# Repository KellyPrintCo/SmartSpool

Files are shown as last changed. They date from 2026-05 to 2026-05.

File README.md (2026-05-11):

# SmartSpool

> **Automatic RFID filament identification for the Bambu Lab AMS 2 Pro.**
> Built and maintained by [Kelly Print Co](https://www.etsy.com/shop/KellyPrintCo).

Load a tagged spool into AMS Slot 1 and your printer instantly knows exactly
what filament is loaded — material, brand, color, and temperatures. No screen
tapping, no manual entry.

This repo contains the open-source firmware, browser extension, and 3D-printable
files. Want the convenience of a pre-built kit? Get one on [Etsy](https://www.etsy.com/shop/KellyPrintCo).

## What's in this repo

| Folder | What it is |
|---|---|
| [`firmware/`](firmware/) | ESP32 firmware — the brain of SmartSpool |
| [`extension/`](extension/) | Print Wizard Chrome extension — adds a guided print button to MakerWorld |
| [`hardware/`](hardware/) | 3D-printable mount STL/3MF files |
| [`version.json`](version.json) | Update manifest — devices fetch this to check for new firmware |
| [`docs-OTA-process.md`](docs-OTA-process.md) | How firmware updates work and how to publish them |

## Quick start

**If you bought a kit:** unbox it, follow the setup card. You're done.

**If you're building it yourself from these files:**

1. **Print the mount** (PETG recommended) from `hardware/stl/`
2. **Wire it up** — ESP32 + MFRC522, see `firmware/README.md` for the wiring diagram
3. **Flash the firmware** — open `firmware/SSOLite.ino` in Arduino IDE 2.x and click Upload
4. **Install the extension** — load `extension/` unpacked in Chrome
5. **Configure** — connect to the `SmartSpool-Setup` Wi-Fi, open `192.168.4.1`, enter your printer info

Full instructions in [`firmware/README.md`](firmware/README.md).

## Features

- **Automatic RFID slot 1 assignment** — tap a tagged spool, AMS updates instantly
- **Custom filament profiles** — unlimited material/brand/color combinations via web UI
- **Auto tag rewrite** *(optional)* — if you change filament info on the printer touchscreen, SmartSpool can update the RFID tag to match
- **Over-the-air updates** — firmware updates push automatically through the Print Wizard extension or device web UI
- **MakerWorld integration** — Print Wizard adds a guided "Print" button that walks beginners through filament check, build plate selection, and bed prep

## Requirements

- Bambu Lab **AMS 2 Pro**
- Bambu Lab **X1, P1, or A1 series** printer
- **LAN Only Mode** and **Developer Mode** enabled on the printer
- 2.4GHz WiFi network
- Components per [`firmware/README.md`](firmware/README.md) parts list

## Compatibility

| Bambu hardware | Status |
|---|---|
| AMS 2 Pro | ✅ Fully supported |
| AMS Lite | ❌ Different mount geometry |
| Original AMS | ❌ Different mount geometry |
| X1C / X1 Carbon | ✅ |
| P1S / P1P | ✅ |
| A1 / A1 mini | ✅ |
| H2D | Not yet tested |

## Releases

Firmware binaries for every release are attached to GitHub releases. The
current stable version is shown in [`version.json`](version.json).

Devices running v1.3.0 or later receive future updates automatically over WiFi.

## License

MIT License — see [LICENSE](LICENSE). You're free to fork, modify, sell, and
distribute. Attribution appreciated but not required.

This project is **not affiliated with Bambu Lab**. SmartSpool uses Bambu's
documented LAN-mode MQTT API and does not modify or interfere with the printer
firmware in any way.

## Contributing

Pull requests and issues welcome. See [`.github/ISSUE_TEMPLATE/`](.github/ISSUE_TEMPLATE/)
for the bug report and feature request templates.

## Support

- **Found a bug?** Open an [issue](https://github.com/KellyPrintCo/SmartSpool/issues/new/choose)
- **Need help with your kit?** Email Kelly Print Co via your Etsy order
- **Want to chat?** Discussions tab on this repo

## Acknowledgments

- Bambu Lab — for building the printer this works with
- The OrcaSlicer team — for documenting the MQTT protocol
- The 3D printing community on r/BambuLab — for being the most helpful corner of the internet

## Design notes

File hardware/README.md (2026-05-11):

# Hardware

This folder holds the 3D-printable parts that make up SmartSpool AMS.

## Files in `stl/`

| File | Description |
|---|---|
| `smartspool-mount.stl` | The main mount that clips into the AMS 2 Pro side slits |
| `smartspool-mount.3mf` | Same file in Bambu 3MF format (preserves print settings) |

## Print settings

- Material: **PETG** (PLA works but warps if AMS drying mode is used)
- Layer height: 0.2mm
- Infill: 20% gyroid
- Walls: 3 perimeters
- Supports: none required if printed in default orientation

## Wiring diagram

See `wiring-diagram.png` (if present) or the wiring section in the firmware README.

## Where to get the files

- This repo: `hardware/stl/` directory
- MakerWorld: search "SmartSpool AMS" for the latest version with photos

## Print yourself, or buy a kit

The STL files here are free to download and print. If you'd rather get a
pre-assembled, pre-flashed kit, look for **Kelly Print Co** on Etsy.

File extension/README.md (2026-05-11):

# MakerWorld Print Wizard for SSO-Lite

A Chrome extension that adds a "Print Wizard" button to MakerWorld model pages
and walks beginners through the whole printing process — checking what
filament is loaded, picking the right one, tagging the spool, choosing the
build plate, and handing the model off to Bambu Studio.

It pairs with **SmartSpool OS Lite (SSO-Lite)** running on your ESP32 + MFRC522
reader, talks to it over your LAN, and uses Studio's existing deeplink to send
the model to your printer. No cloud, no server, no extra software.

## How it works

```
You browse a model on MakerWorld
        │
        │  ① extension injects "Print Wizard" button
        ▼
  Wizard opens as an overlay
        │
        │  ② calls SSO-Lite over LAN (HTTP) to read AMS Slot 1
        ▼
  Wizard checks if the loaded filament matches what the model needs
        │
        │  ③ if not, you pick a profile and tap a tag — SSO-Lite writes the
        │     tag and pushes the new filament to AMS Slot 1 over MQTT
        ▼
  Wizard confirms the printer is ready (plate, bed prep)
        │
        │  ④ clicks MakerWorld's own "Open in Studio" link
        ▼
  Bambu Studio opens with the model — you click Print
```

The extension never talks to the printer directly. All printer communication
goes through the SSO-Lite firmware (which you already have running for AMS
auto-assignment). Studio handles the actual print job.

## Install

This is an **unpacked extension** — Chrome's developer load mode. Five steps:

1. **Update SSO-Lite firmware to v1.1.0** (see `SSOLite.ino` in the SSO-Lite
   project folder). The new version adds CORS headers (so the browser can call
   it) and an mDNS responder (so the extension can find it as `ssolite.local`).
   Re-flash from Arduino IDE; everything keeps working as before.

2. Download or clone this folder somewhere stable on your Mac/PC. Don't put
   it in Downloads or it'll go away when you clean up.

3. Open Chrome and go to `chrome://extensions`.

4. Toggle **Developer mode** on (top-right corner of that page).

5. Click **Load unpacked** and pick the `mw-print-wizard/` folder.

The extension's icon (a green spool) should appear in your toolbar. If
you don't see it, click the puzzle-piece icon and pin it.

## First use

1. Click the toolbar icon. The popup shows whether it can reach SSO-Lite.
2. If it says "unreachable", click **Settings**:
   - Most users: leave address as `ssolite.local`. This works on macOS and
     iOS out of the box, on Windows 10+ it usually works, on Linux it works
     if you have Avahi/`avahi-daemon` installed.
   - If `ssolite.local` doesn't resolve, replace it with the device's IP
     address (you can find this in your router's DHCP table or in the
     SSO-Lite serial monitor at boot).
   - Click **Test connection**. You should see "Connected (vX.X.X)."
   - Click **Save**.
3. Open any model page on `https://makerworld.com/...`. Look for the green
   **Print Wizard** button next to MakerWorld's regular Print/Open in Studio
   button. (If MakerWorld redesigns and the button can't find an anchor, it
   floats in the bottom-right corner instead.)
4. Click it. Walk through the wizard.

## What the wizard does, step by step

| Step | What happens |
|---|---|
| **Welcome** | Shows the model title, image, recommended materials and plate (scraped from the page). |
| **Connect** | Verifies SSO-Lite is reachable. Shown only on first use; skipped after the first successful connection in a wizard session. |
| **Filament check** | Asks SSO-Lite what's currently in AMS Slot 1, compares against the page's recommended materials. Big green ✓ if they match, big yellow ⚠ if they don't. |
| **Pick filament** *(only if mismatched)* | Shows your SSO-Lite profile library as a grid of color-coded cards. Profiles whose material matches the model are pinned to the top with a "recommended" badge. |
| **Load & tag** *(only if swapping)* | Tells you to load the spool and tap the tag. Live status — polls SSO-Lite every 800ms, advances when a successful read of the chosen profile is detected. |
| **Build plate** | Shows what plate the model wants, with a beginner-friendly explanation. Requires you to tick "the right plate is on my printer" before continuing. |
| **Quick prep** | Four-item checklist: clean bed, plate seated, nozzle clear, door position. All four must be ticked. |
| **Send to Studio** | Clicks MakerWorld's existing "Open in Studio" link. Studio opens with the model loaded; you press Print there. |
| **Done** | A short reminder to watch the first layer. |

## What about the "MQTT verification failed" error?

The wizard inherits SSO-Lite's solution: your printer needs to be in **LAN
Only Mode + Developer Mode**. Without it, MQTT commands (the AMS slot
assignment) get rejected. See the SSO-Lite README's troubleshooting section.

If you're keeping cloud mode (e.g. you need Bambu Handy via cloud), turn off
SSO-Lite's auto-assign and the wizard will still walk you through everything
useful — it just won't push the AMS change. You set the slot manually in
Studio.

## Files

| File | Purpose |
|---|---|
| `manifest.json` | MV3 manifest. Permissions, content-script targets, web-accessible resources. |
| `background.js` | Service worker. Owns the SSO-Lite HTTP client and the settings store. Everything else talks to it via `chrome.runtime.sendMessage`. |
| `content.js` | Injected into MakerWorld pages. Detects model pages, scrapes metadata, injects the button, opens the wizard iframe. |
| `content.css` | Button + iframe overlay styling. Namespaced with `.sso-mw-` to avoid collisions with MakerWorld's own classes. |
| `wizard.html` / `wizard.js` / `wizard.css` | The wizard itself. Runs inside an iframe that the content script injects. Communicates with the parent (content script) via `postMessage` and with SSO-Lite via the background worker. |
| `popup.html` / `popup.js` / `popup.css` | Toolbar popup — health check + quick links. |
| `options.html` / `options.js` | Settings page — SSO-Lite hostname/IP/port, test button. |
| `icons/` | 16/48/128 PNG icons. |

## Permissions explained

| Permission | Why we need it |
|---|---|
| `storage` | Remember your SSO-Lite hostname between sessions. |
| `host_permissions` for `*.makerworld.com` | Inject the content script on model pages. |
| `host_permissions` for `http://ssolite.local/*` and `http://*/*` | Talk to SSO-Lite over LAN. The wildcard `http://*/*` is there so users can use a raw IP (which we can't predict). MV3 service workers need explicit host permission to fetch cross-origin. |

The extension does **not** read or send anything to any cloud service. All
network traffic goes either to MakerWorld (you're already there) or to your
own SSO-Lite device on your LAN.

## Troubleshooting

**"Print Wizard" button never appears on MakerWorld**
- Open the page DevTools → Console. The content script logs once at load.
- MakerWorld may have changed their DOM. As a fallback the button auto-floats
  to the bottom-right corner if the script can't find the regular Print
  button anchor.
- Make sure the URL matches `/models/` — the script ignores other pages.

**Wizard says "Couldn't reach SSO-Lite"**
- Open the toolbar popup. If it's also unreachable from there:
  - Open `http://ssolite.local/` directly in a new tab. If that doesn't load,
    you have an mDNS issue — switch to the IP in Settings.
  - Make sure SSO-Lite is on the same Wi-Fi as your computer. Some "guest"
    networks block client-to-client traffic.
  - Check the SSO-Lite serial monitor — does it print `[mDNS] http://ssolite.local/` at boot?

**"Tag write" times out**
- The wizard polls for 65 seconds. If you didn't tap a tag in time, click
  back and re-pick the profile.
- Make sure the SSO-Lite reader's LED is doing its boot-blink — if it
  isn't, the ESP32 isn't powered.

**Studio doesn't open at the end**
- Make sure Bambu Studio is installed (`bambustudio://` deeplinks need it).
- If MakerWorld's own "Open in Studio" button doesn't work either, the
  problem is upstream of us.
- The wizard shows a fallback message in the "Send" step if it can't find
  the link.

## License

Same as SSO-Lite. Not affiliated with Bambu Lab or MakerWorld.

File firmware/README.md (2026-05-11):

# SmartSpool OS Lite (SSO-Lite) — Complete Build Guide

ESP32 + MFRC522 → Bambu Lab AMS Slot 1 auto-assignment over MQTT/TLS.

This document is the full design, build, troubleshooting, and productization guide.
The firmware itself lives in `SSOLite.ino` and `web_pages.h` — open them in Arduino IDE
and flash. No other configuration is needed at compile time; everything is set through
the on-device web UI.

---

## What's New in v1.3.0

**Over-the-air firmware updates** *(new feature)*

SmartSpool can now update its own firmware over WiFi — no USB cable, no
Arduino IDE, no manual flashing. The update prompt appears automatically when
Print Wizard connects to a device running an older version, or in the device's
own web UI under Controls → Firmware Update.

How it works:
1. SmartSpool checks `version.json` on GitHub for the latest published firmware
2. If an update is available, the web UI / Print Wizard shows an update prompt
3. The new firmware binary downloads from GitHub Releases
4. The binary uploads to the SmartSpool device over LAN (~5 seconds)
5. SmartSpool's `Update` library writes it to the OTA partition
6. Device reboots and comes back on the new firmware (~10-15 seconds)
7. Web UI / Print Wizard auto-reconnects and verifies the new version

The whole process takes 25-40 seconds end to end on a typical home network.

Configuration:
- Firmware author edits `version.json` in the GitHub repo to publish updates
- New endpoint `POST /api/update` accepts firmware binaries
- New endpoint `GET /api/update/status` reports upload progress
- See `OTA_RELEASE_GUIDE.md` for the full release publishing process

**Important chicken-and-egg note:** Devices running firmware older than v1.3.0
do not have the OTA endpoint and must be flashed to v1.3.0 via USB once.
After that, all future updates can be OTA. Ship pre-flashed units with v1.3.0+
to avoid customers ever encountering this.

---

## What's New in v1.2.0

**Auto-rewrite on touchscreen change** *(new, off by default)*

When enabled, if you change slot 1 filament info on the printer's touchscreen
(color, brand, material, temps), SmartSpool catches the change via MQTT and
queues a rewrite of the RFID tag. The next time you tap that tag on the reader,
the new info is written to the tag automatically — no need to use the SmartSpool
web UI to manually update each tag.

How it works:
1. You scan tag A → SmartSpool reads it and applies its profile to slot 1.
2. You change filament info on the touchscreen (different color, brand, etc.).
3. The printer publishes the new state over MQTT.
4. SmartSpool detects this is *different* from what it just set, and queues the
   new info as a "pending rewrite" tied to tag A's UID.
5. Next time tag A is presented to the reader, SmartSpool writes the new info
   to the tag before doing the normal scan flow. Tag now persists the change.

Off by default because some users intentionally do one-off touchscreen overrides
they don't want remembered. Enable it via:
- Web UI → Setup tab → "Auto-rewrite tag on touchscreen change"
- Web UI → Controls → "Toggle Auto-Rewrite" button
- API: `POST /api/rewrite`

A pending rewrite is shown on the dashboard with a yellow card; you can cancel
it before scanning.

**Side-slit mounting** *(mechanical change)*

The recommended mount location is now the side slits on the *outside* of the
AMS 2 Pro, not the desiccant slot. This avoids any conflict with the AMS lid
opening, the drying chamber, or internal cable routing. The reader still has
range to read tags on a spool loaded into slot 1.

---

## 1. System Architecture

```
 ┌──────────────┐     SPI      ┌──────────────────┐    Wi-Fi/TLS   ┌─────────────┐
 │  RFID Tag    │◀────────────▶│      ESP32       │───────────────▶│   Bambu     │
 │ (MIFARE 1K)  │   MFRC522    │  (SSO-Lite FW)   │   MQTT 8883    │   Printer   │
 └──────────────┘              │                  │   bblp / LAN   │  (X1/P1/A1) │
                               │  • Web UI :80    │                │             │
                               │  • Profile DB    │                │  AMS Slot 1 │
                               │  • UID fallback  │◀───────────────│  (tray 0,0) │
                               └──────────────────┘   /report      └─────────────┘
```

### Data flow
1. Tag enters RF field → MFRC522 returns UID and authenticates sector 1 with default key A.
2. ESP32 reads blocks 4–6 (48 bytes), validates magic header `SSO1`, parses compact key=value payload.
3. The parsed Bambu code (e.g. `GFL99`) is resolved against the on-device profile database to canonicalise temps and color.
4. ESP32 publishes `ams_filament_setting` to `device/{serial}/request` over MQTT/TLS.
5. Printer applies the change; the next `/report` push confirms the new tray state.

### Tag lifecycle
```
   blank tag ──► [Web UI: Queue Write] ──► written tag ──► scanned ──► assigned ──► reused
                                                  │                            ▲
                                                  └───── Edit ─────────────────┘
```

### State machine
| State | Trigger | Exit |
|---|---|---|
| BOOT | power-on | config loaded → WIFI_CONNECTING |
| WIFI_CONNECTING | startup / disconnect | got IP → MQTT_CONNECTING |
| MQTT_CONNECTING | TCP up | broker ack → IDLE |
| IDLE | nothing happening | tag presented → READING; UI write queued + tag → WRITING |
| READING | card detected | parse OK → ASSIGNING; parse fail → UID fallback or ERROR |
| WRITING | pending write fulfils | success → IDLE; failure → ERROR |
| ASSIGNING | auto-assign on | publish OK → IDLE; publish fail → retry queue |
| ERROR | any failure | LED blink, log, return to IDLE |

### Failure handling
- **Wi-Fi drop**: 10 s reconnect loop; web UI stays up on STA IP, AP fallback if SSID unconfigured.
- **MQTT drop**: 5 s reconnect; pending assign request is held in `g_pending` and re-sent on reconnect with exponential backoff (5/10/20/40/80 s).
- **Tag corruption**: checksum mismatch logs a warning but the parser is forgiving — partial fields recover. If the magic header itself is gone, UID-fallback table maps `(UID → code)`.
- **AMS override / drift**: `processReport()` watches the printer's reported tray 0 code; if it differs from the last-scanned profile, SSO-Lite re-applies once per 30 s.
- **Bambu official RFID detected**: non-Classic tag types (NTAG/Ultralight) trigger `g_officialTagDetected = true`, auto-assign is suppressed, and the dashboard pill turns yellow.

---

## 2. Hardware Design

### Parts list
| Item | Qty | Notes |
|---|---|---|
| ESP32 DevKit V1 / WROOM-32 / NodeMCU-32S | 1 | Any 30/38-pin board with native USB |
| MFRC522 RFID module | 1 | Common red breakout, 3.3 V logic |
| MIFARE Classic 1K white card / sticker | n | The "blue" 13.56 MHz cards from any vendor |
| Dupont jumpers (F-F) | 7 | One per signal + VCC/GND |
| USB-C / micro-USB cable | 1 | Power + flashing |
| 3D-printed mount (Section 13) | 1 | optional but recommended |

### Wiring (ESP32 ↔ MFRC522)

| MFRC522 | ESP32 GPIO | Function | Notes |
|---|---|---|---|
| SDA / SS | **GPIO 5** | SPI chip-select | safe pin |
| SCK | **GPIO 18** | SPI clock | VSPI default |
| MOSI | **GPIO 23** | SPI MOSI | VSPI default |
| MISO | **GPIO 19** | SPI MISO | VSPI default |
| RST | **GPIO 22** | reset | safe pin |
| GND | **GND** | ground | |
| 3V3 | **3V3** | **3.3 V ONLY** | see warning below |
| IRQ | (not connected) | — | unused; we poll |

> ⚠️ **3.3 V ONLY.** Many MFRC522 boards say "3.3 V or 5 V" on the silkscreen.
> The MFRC522 IC itself is **only** 3.3 V. Powering from 5 V will work briefly and then
> kill the chip. Use the ESP32's 3V3 pin (which can sink ~500 mA — plenty for this module).

### Pins to AVOID on ESP32

| Pin | Why |
|---|---|
| GPIO 0 | Boot strap — must be HIGH at reset to boot from flash |
| GPIO 2 | Boot strap & on-board LED on most boards |
| GPIO 12 | Boot strap — wrong level locks board into 1.8 V flash mode |
| GPIO 15 | Boot strap — pulled up enables verbose serial spam |
| GPIO 6–11 | Connected to internal SPI flash — touching these bricks the boot |
| GPIO 34–39 | Input-only, no internal pull-ups |

The pins chosen (5, 18, 19, 22, 23) are all general-purpose and free of strap conflicts.

### Physical placement near AMS Slot 1

For an AMS or AMS Lite, the ideal mount point is on the **outer face of the slot 1
filament guide**, with the MFRC522 antenna oriented so that a tag stuck to the side of
the spool (or a separate tag on a hook) passes within ~25 mm of the coil during loading.
Tag read range with a Classic 1K card and a default-tuned MFRC522 is ~30–40 mm.

A 3D-printable bracket is described in Section 13.

---

## 3. RFID Tag System

### A. Storage strategy

MIFARE Classic 1K = 16 sectors × 4 blocks × 16 bytes = 1024 bytes total.

```
Sector 0  Block 0   manufacturer block (UID + data) — READ ONLY
Sector 0  Block 1   usable, but we avoid (some clones break here)
Sector 0  Block 2   usable, but avoided
Sector 0  Block 3   sector trailer (keys + ACL) — DO NOT WRITE
Sector 1  Block 4   ◄── SSO data block A
Sector 1  Block 5   ◄── SSO data block B
Sector 1  Block 6   ◄── SSO data block C
Sector 1  Block 7   sector trailer — DO NOT WRITE
Sectors 2-15        free for future extensions
```

We use **only sector 1**, blocks 4–6 (48 bytes total). This is enough for the compact
encoded format and leaves the rest of the card available for future features (usage
counters, cloning detection, etc.).

### B. Data formats

#### Compact (on-tag, what SSO-Lite reads/writes)
```
M=PLA;C=GFL99;X=000000;B=Overture;N=210;D=60
```
Fields:
- `M` — material short name (PLA / PETG / ABS / TPU / PA / PC / PVA)
- `C` — Bambu generic code (`tray_info_idx`, e.g. `GFL99`)
- `X` — color RGB hex (no `#`, no alpha)
- `B` — brand name (≤ 19 chars)
- `N` — nominal nozzle temp (printer recomputes range)
- `D` — bed temp

The parser is order-independent and tolerant of missing optional fields.

#### Full JSON (used in HTTP API + persistent storage)
```json
{
  "name": "Overture PLA Matte",
  "material": "PLA",
  "code": "GFL99",
  "color": "1C1C1C",
  "brand": "Overture",
  "nozzle_min": 200,
  "nozzle_max": 220,
  "bed": 60,
  "flow_x1000": 1000
}
```

#### Tag block layout (48 bytes)
| Bytes | Content |
|---|---|
| 0–3 | magic `S S O 1` (`0x53 0x53 0x4F 0x31`) |
| 4 | version (`0x01`) |
| 5 | payload length N (≤ 41) |
| 6 .. 5+N | ASCII payload |
| 5+N .. 46 | zero padding |
| 47 | XOR checksum of bytes 0..46 |

### C. Tag security
- **Keys:** SSO-Lite uses the default factory key A (`FF FF FF FF FF FF`) on sector 1.
  Keeping the default keeps tags re-flashable from any standard tool and avoids the
  *brick-on-typo* failure mode. If you want to lock tags, you can change Key A in the
  sector trailer — but **never touch block 7 unless you understand MIFARE access bits**;
  one bad write permanently locks the sector.
- **Overwrite protection:** The web UI requires an explicit "Queue Write" press; the
  reader will only write within a 60 s window per request. A tag presented outside that
  window is read-only.
- **UID fallback:** every successful write also stores `(UID → tray_info_idx)` in the
  device's UID map. If the data blocks ever go bad, SSO-Lite still recognises the spool
  by UID and applies the right profile.

---

## 4. Filament Profile System

Profiles live in NVS (`Preferences`) and are loaded into `g_profiles[]` at boot.
On first boot, the firmware seeds a starter set:

| Name | Material | Code | Color | Brand | Nozzle | Bed |
|---|---|---|---|---|---|---|
| Generic PLA Black  | PLA  | GFL99 | #000000 | Generic  | 190–230 | 60 |
| Generic PLA White  | PLA  | GFL99 | #FFFFFF | Generic  | 190–230 | 60 |
| Generic PLA Red | PLA  | GFL99 | #C8161D | Generic  | 190–230 | 60 |
| Generic PLA Blue | PLA  | GFL99 | #0066CC | Generic  | 190–230 | 60 |
| Overture PLA Matte | PLA  | GFL99 | #1C1C1C | Overture | 200–220 | 60 |
| Generic PETG | PETG | GFG99 | #0099A8 | Generic  | 230–255 | 75 |
| Generic PETG Black | PETG | GFG99 | #000000 | Generic  | 230–255 | 75 |
| Generic ABS | ABS  | GFB99 | #F2F2F2 | Generic  | 240–270 | 95 |
| Generic TPU 95A | TPU  | GFU99 | #FFFFFF | Generic  | 220–240 | 50 |
| Generic PA (Nylon) | PA | GFN99 | #303030 | Generic  | 260–290 | 80 |
| Generic PC | PC | GFC99 | #F0F0F0 | Generic  | 270–290 | 100 |
| Generic PVA Sup. | PVA  | GFS99 | #F4E2B8 | Generic  | 200–210 | 60 |

**Bambu generic codes** are 5-character `tray_info_idx` values that tell the printer to
treat the slot as the corresponding generic profile (slicer-side). The `GF*99` codes
above are the widely-documented community-known values; if your printer firmware uses
different ones, edit the seed list in `seedDefaultProfiles()` or change the code in the
profile from the web UI.

**Lookup logic:**
1. Tag scanned → compact payload parsed → `code` extracted.
2. `findProfileByCode(code)` returns the canonical local profile (full temps, brand, name).
3. If no local match exists, the tag's own values are used directly.

Profiles are user-editable from the **Profiles** tab. Up to 32 profiles fit; deleted
slots are reused automatically.

---

## 5. Tag Writing System

### A. Write mode
Used for blank tags and for overwriting existing SSO tags. Implementation in
`writeTagData()`:

1. Encode profile → compact ASCII payload.
2. Build 48-byte blob: magic + version + length + payload + zero pad + checksum.
3. For each of blocks 4, 5, 6:
   - Authenticate with default Key A.
   - `MIFARE_Write(block, data, 16)`.
4. Update UID-map entry `(UID → code)` and persist.

### B. Update mode
Field-level edits are done by **reading first, merging, then writing the whole 48-byte
blob**. This is safer than partial-block writes (MIFARE writes are always 16 bytes) and
keeps the checksum valid.

```
read tag → decode profile → patch fields from web form → encode → write tag
```

### C. UI integration
1. User opens **Tag Manager** tab.
2. Picks a profile from the dropdown (or hits a Quick-Write preset).
3. Presses **Queue Write**.
4. ESP32 enters write-armed state for 60 s.
5. User taps the tag on the reader.
6. LED double-flashes on success, 5-flashes on failure.

---

## 6. MQTT Implementation (Bambu LAN mode)

### Connection parameters
| Setting | Value |
|---|---|
| Host | printer's LAN IP |
| Port | `8883` |
| Transport | TLS (self-signed cert; we use `setInsecure()`) |
| Username | `bblp` |
| Password | LAN access code (printer screen → Settings → WLAN → Access Code) |
| Client ID | `SSOLite-{efuseMacHex}` (must be unique per printer connection) |
| Keepalive | 30 s |

### Topics
| Direction | Topic |
|---|---|
| publish | `device/{serial}/request` |
| subscribe | `device/{serial}/report` |

### Assignment command
```json
{
  "print": {
    "sequence_id": "12345",
    "command": "ams_filament_setting",
    "ams_id": 0,
    "tray_id": 0,
    "tray_info_idx": "GFL99",
    "tray_color": "000000FF",
    "nozzle_temp_min": 190,
    "nozzle_temp_max": 230,
    "tray_type": "PLA"
  }
}
```

`tray_color` is **RGBA** (8 hex chars). SSO-Lite always appends `FF` for full alpha.

### Confirming the assignment
The printer pushes the new tray state in the next `/report` message. SSO-Lite filters
the JSON to just `print.ams.ams[0].tray[0]` and updates `g_currentSlot1`. The web UI
shows this as the live "AMS Slot 1" swatch.

If the reported `tray_info_idx` ever drifts away from the last scanned profile (e.g. the
user reset the AMS or the slicer overrode it), SSO-Lite reapplies the assignment once,
rate-limited to one reapply per 30 s.

### Timing constraints
- Allow up to ~2 s after publish for the printer to apply the change.
- Don't burst commands faster than one per second; the printer will accept them but the
  AMS UI updates rate-limit.
- During an active print, AMS slot edits are still accepted but won't change the
  currently-loaded filament until the next `M620` (filament change).

### Retry logic
```
publish → ok? ┬─ yes: clear pending
              └─ no:  attempts++, next_attempt = now + 5s × 2^min(attempts,4)
                      stored in g_pending, retried in main loop
```

---

## 7. ESP32 Firmware

The complete firmware is in `SSOLite.ino` + `web_pages.h`. Key modules:

| Module | Where | Responsibility |
|---|---|---|
| State + globals | top of `SSOLite.ino` | configuration, last scan, history, pending |
| Persistence | `loadConfig/saveConfig`, `loadProfiles/saveProfiles`, `loadUidMaps/saveUidMaps` | NVS via `Preferences` |
| Defaults | `seedDefaultProfiles()` | runs once on first boot |
| RFID | `initRFID`, `rfidPoll`, `handleTag`, `readTagData`, `writeTagData`, `authBlock`, `encodeProfile`, `decodeProfile` | MFRC522 driver wrapper, parser, encoder |
| Wi-Fi | `initWiFiSTA` | STA with AP fallback to `SSOLite-Setup` / `spool1234` |
| MQTT | `initMQTT`, `sendAmsAssign`, `mqttCallback`, `processReport` | TLS connect, publish, filtered subscribe |
| Web | `initWebServer` + `api*()` handlers | REST + static HTML/CSS/JS |
| Helpers | `uidToHex`, `xorChecksum`, `setLED`, `blinkLED` | utility |

All the firmware features required by the spec are implemented:
- ✅ MFRC522 read/write (3-block payload + checksum)
- ✅ Compact format parsing
- ✅ JSON parsing (HTTP + MQTT report filter)
- ✅ Profile mapping with code/name lookups
- ✅ Wi-Fi STA + AP fallback
- ✅ MQTT TLS to Bambu LAN
- ✅ Auto-assign with debounce + duplicate protection
- ✅ Retry queue with exponential backoff
- ✅ UID fallback mapping
- ✅ Embedded web UI on port 80
- ✅ Serial debug logging at 115200 baud

---

## 8. Web UI

Hosted on the ESP32 at `http://<device-ip>/`. All UI assets are PROGMEM strings in
`web_pages.h` — no external CDN, works fully offline.

### Tabs

**Dashboard**
- Live AMS Slot 1 swatch + code
- Last scanned tag (color, name, UID, source: tag / uid_map)
- Connection pills (Wi-Fi, MQTT, auto-assign, official-tag lock)
- Last 5 scans (color-coded history)

**Tag Manager**
- Select profile + "Queue Write"
- Quick-Write preset buttons (one per profile, color-bordered)
- Cancel queued write

**Profiles**
- List of all profiles with edit/delete buttons
- Add/edit form (name, brand, material, code, color picker, temps)

**Controls**
- Force assign (sends MQTT without scanning a tag)
- Toggle auto-assign
- Reboot device

**Setup**
- Wi-Fi SSID/password
- Printer IP / serial / LAN access code
- Auto-assign default

The UI polls `/api/status` every 1.5 s for live updates.

---

## 9. Auto-Assignment Logic

```
                       ┌────────────────────────────────────┐
                       │                                    │
   tag in field ──► debounce (3s on same UID) ──► read 3 blocks
                                                  │
                       (read fails)               │ (read ok)
                       │                          ▼
                       ▼                  decode compact payload
                 UID-map lookup            │
                       │                   │
                 (no map → drop)           ▼
                       │             resolve to local profile
                       │                   │
                       └───────► merge ◄───┘
                                          │
                                          ▼
                                 push to history
                                          │
                                  auto-assign on?
                                  │            │
                                 no            yes
                                  │            │
                                  └─► idle     ▼
                                          publish MQTT
                                          │       │
                                         ok       fail
                                          │       │
                                          ▼       ▼
                                    g_currentSlot1   pending+backoff
```

- **Debounce:** 3000 ms on identical UID prevents bouncing reads from firing 10 commands.
- **Duplicate protection:** if the same profile code is already loaded in slot 1 *and*
  was set by us, we still publish (the user might have clicked a quick-write preset for
  a reason); but the report watcher won't trigger drift correction in this case.
- **Reapply on AMS reset:** the report processor compares reported `tray_info_idx`
  against `g_lastScan.profile.code` and reapplies once per 30 s if they differ.

---

## 10. Edge Case Handling

| Edge case | Behavior |
|---|---|
| Tag completely unreadable | `readTagData()` returns false → `findUidMap()` lookup → if hit, use mapped profile; if miss, log + LED 4-blink |
| Tag partially corrupted | parser is forgiving: missing fields are filled with defaults, decoder still returns true if `code` and `material` present |
| Checksum mismatch | warning logged, parser still attempts decode |
| MQTT broker down | publish queued in `g_pending`, retried with exponential backoff (5/10/20/40/80 s cap) |
| Wi-Fi drops | 10 s reconnect loop; web UI remains available on AP fallback if SSID gone |
| AMS override (user changed slot manually) | `processReport()` sees drift → reapplies last scanned profile (max once / 30 s) |
| Bambu official RFID spool inserted | non-Classic tag type detected → `g_officialTagDetected=true`, auto-assign suppressed, dashboard shows yellow lock pill |
| Multiple AMS units present | hard-pinned to `ams_id=0`, `tray_id=0` per spec |
| Profile slots full | API returns 507; UI shows error; user must delete a profile |
| Write request without tag in 60 s | request expires, `g_pendingWrite.pending = false` |

---

## 11. Step-by-Step Setup Guide

(As if you were 13 and have never built one of these.)

### Things you need
- An ESP32 board (the rectangular dev-kit one with a USB port).
- An MFRC522 reader (the red one with a coil on the front).
- 7 jumper wires (female-to-female).
- 5 blank MIFARE 1K cards (the blue ones, 13.56 MHz — *not* the white 125 kHz ones).
- A computer with Arduino IDE installed.
- The Wi-Fi name & password.
- Your Bambu printer's IP address and LAN access code.

### Step 1 — Wire it up
With both modules **unpowered**, connect:

| MFRC522 pin | ESP32 pin |
|---|---|
| SDA | GPIO 5 |
| SCK | GPIO 18 |
| MOSI | GPIO 23 |
| MISO | GPIO 19 |
| RST | GPIO 22 |
| GND | GND |
| 3.3V | 3V3 |
| IRQ | (leave empty) |

Double-check 3.3V. **Never** wire it to 5V; the chip will die.

### Step 2 — Install Arduino IDE & libraries
1. Download Arduino IDE 2.x from arduino.cc.
2. **File → Preferences → Additional Board Manager URLs**, paste:
   `https://espressif.github.io/arduino-esp32/package_esp32_index.json`
3. **Tools → Board → Boards Manager**, search "esp32", install Espressif's package.
4. **Tools → Manage Libraries**, install:
   - `MFRC522` by GithubCommunity / Miguel Balboa (≥ 1.4.10)
   - `PubSubClient` by Nick O'Leary (≥ 2.8)
   - `ArduinoJson` by Benoit Blanchon — pick **version 6.21.x** (NOT v7).

### Step 3 — Flash the firmware
1. Open `SSOLite.ino` in Arduino IDE — `web_pages.h` opens automatically as a tab.
2. **Tools → Board** → "ESP32 Dev Module".
3. **Tools → Port** → the COM port that appeared when you plugged in the ESP32.
4. **Tools → Partition Scheme** → "Default 4MB with spiffs" is fine.
5. Click the **Upload** arrow. If the ESP32 won't enter download mode, hold the BOOT
   button while it says "Connecting…".
6. Open **Serial Monitor** at **115200 baud**. You should see:
   ```
   ===== SmartSpool OS Lite v1.0.0 =====
   [PROFILES] seeded 12 defaults
   [RFID] MFRC522 firmware version: 0x92
   [WiFi] No SSID configured. Starting AP 'SSOLite-Setup'...
   [WiFi] AP IP: 192.168.4.1
   [WEB] HTTP server on :80
   [BOOT] Ready.
   ```

### Step 4 — Connect to the device's setup AP
On your phone or laptop, connect to Wi-Fi:
- SSID: `SSOLite-Setup`
- Password: `spool1234`

Open `http://192.168.4.1` — the SSO-Lite web UI loads.

### Step 5 — Get your printer's info
On the Bambu printer screen:
- Settings → WLAN — note the **IP address**.
- Settings → WLAN → "Access Code" (LAN-only mode must be enabled).
- Settings → Device → **serial number** (starts with `01`, `02`, `03`, or similar).

### Step 6 — Configure SSO-Lite
In the web UI → **Setup** tab:
1. Wi-Fi SSID + password (your home Wi-Fi, the one the printer is on).
2. Printer IP, serial, LAN access code.
3. ✅ Auto-assign on scan.
4. Save.
5. The device reboots and joins your home Wi-Fi. Find its new IP from your router or
   serial monitor, and reload the UI from there.

When MQTT connects, the dashboard's MQTT pill turns green and the AMS Slot 1 swatch
populates.

### Step 7 — Write your first tag
1. Tag Manager tab → pick "Generic PLA Black".
2. Click **Queue Write**.
3. Tap a blank MIFARE 1K card on the reader within 60 s.
4. Watch the serial monitor — you should see:
   ```
   [RFID] tag UID=A1B2C3D4
   [WRITE] writing pending profile to tag...
   [WRITE] result: OK
   ```

### Step 8 — Test auto-assign
Tap the same tag on the reader without queueing a write. You should see:
```
[RFID] tag UID=A1B2C3D4
[RFID] payload: M=PLA;C=GFL99;X=000000;B=Generic;N=210;D=60
[ASSIGN] publish device/01P00.../request: OK
```
Look at the printer — AMS Slot 1's filament should switch to "Generic PLA" with black color.

You're done. 🎉

---

## 12. Troubleshooting

### MFRC522 not reading anything (`firmware version: 0x00` or `0xFF`)
- Wiring: check SDA/SS goes to GPIO 5 specifically (the firmware hard-codes it).
- Power: the module **must** be on 3.3 V. If you ran it on 5 V, the chip is probably dead.
- Cold solder joints on the breakout's pin header — reflow them.
- Long Dupont wires can drop SPI clock — keep wires under 15 cm and twist GND with each signal if you must run them longer.

### Boot loop / "Brownout detector triggered"
- USB cable is power-only or current-limited. Try another cable, ideally USB-C.
- Drawing too much from a weak USB port — plug into a 1 A+ supply.

### "Failed to connect to ESP32" at flash time
- Hold the **BOOT** button while clicking Upload, release when "Writing…" starts.
- Try a different USB port. Some hubs don't pass the auto-reset signal.

### Wi-Fi connects but MQTT fails (rc=-2 or rc=5)
- rc=-2 → cannot reach host: wrong IP, or Wi-Fi VLAN isolation is blocking.
- rc=5 → bad credentials: username MUST be `bblp` (lowercase), password is the LAN access code (not the cloud password).
- Make sure **LAN-only mode** or **LAN access code** is enabled on the printer screen. Without it, port 8883 is closed.
- Some firewalls block self-signed TLS — verify the printer is reachable: `openssl s_client -connect <ip>:8883`.

### TLS handshake fails
- The firmware uses `tlsClient.setInsecure()` which accepts the self-signed cert. If you removed that line for security, you need to embed the printer cert; see ESP32 `WiFiClientSecure::setCACert()`.

### AMS not updating
- Verify the assign command was published: serial log shows `[ASSIGN] publish ... OK`.
- Verify `ams_id=0, tray_id=0` corresponds to physical slot 1 (it does on AMS / AMS Lite).
- The slicer can override AMS settings at print start. After slicing, recheck slot 1.
- Some printer firmware versions reject the command silently if the AMS is mid-load. Wait for AMS idle and retry from the **Force Assign** button.

### Wrong filament code applied
- The Bambu generic codes (`GFL99` etc.) sometimes change between firmware versions. If your printer doesn't recognise the code, edit the profile via the Profiles tab and try alternates (community-known codes include `GFL99`, `GFL00`, `GFL98` for Generic PLA depending on firmware).
- Verify by clicking the "Force Assign" button while watching the printer screen — the change is instant if accepted.

### LED behaviour
| Pattern | Meaning |
|---|---|
| 3 short blinks at boot | system ready |
| solid on briefly | tag in field, processing |
| 2 blinks | success (read or write) |
| 4 blinks | tag unreadable + no UID map |
| 5 blinks | write failed |

### "Boot pin conflicts" / serial spam
Don't add buttons or external pull-ups on GPIO 0/2/12/15. If you previously wired RST to GPIO 0 (some ancient tutorials do), move it to GPIO 22 as in this build.

---

## 13. Productization Plan

A path from "working hack" to "kit you can ship".

### Mechanical (MakerWorld / Printables release)
- **Printer mount**: clip-on bracket for AMS or AMS Lite slot 1 outer face. ESP32 sits on
  the back, MFRC522 antenna faces outward. Print in PETG (avoid PLA — heat sensitive).
- **Tag holder**: 38 mm disc that snaps onto a spool's outer rim with a recess for a 25 mm
  MIFARE sticker. Two designs: rim-clip and adhesive.
- **Enclosure**: two-part snap-fit, 65 × 45 × 20 mm, with USB-C cutout, MFRC522 antenna
  window, and an LED light pipe.

### Kit BOM (target retail $35)
| Item | Cost |
|---|---|
| ESP32 WROOM-32 module | ~$4 |
| MFRC522 breakout | ~$2 |
| 10 × MIFARE 1K stickers | ~$3 |
| Pre-soldered ribbon harness | ~$1 |
| Printed enclosure + mount | ~$2 |
| USB-C cable | ~$2 |
| Box + insert + manual | ~$3 |
| **COGS** | **~$17** |

### UX improvements for a shipped product
- **Setup QR system**: device boots with a unique AP password printed on a sticker;
  scanning a QR autofills SSID/password and links to `http://192.168.4.1`.
- **OTA updates**: replace the manual flash step with `ArduinoOTA` once the device joins
  Wi-Fi.
- **Pre-flashed tags**: ship 5 stickers already programmed for "PLA Black/White" + 1 PETG
  + 1 ABS + 2 blank.
- **Mobile-first UI**: the current UI is responsive but could be wrapped in a Capacitor
  shell for a friendlier "app".
- **mDNS hostname**: announce as `ssolite.local` so users don't need to find the IP.

### Compliance considerations
- FCC Part 15 unintentional-radiator compliance: an ESP32 module used inside an enclosure
  with no RF amplification is generally covered by the module's own FCC-ID (e.g. ESP-WROOM-32:
  2AC7Z-ESPWROOM32) as long as the antenna isn't modified.
- CE: same logic with the module's RED CE mark.

---

## 14. Advanced Features (already implemented)

### Tag cloning prevention
Each tag's UID is stored in the UID-map alongside the code at write time. When a *different*
UID is presented for the same code, the firmware accepts it but logs a warning. A future
extension (sector 2) can store an HMAC of `(UID || payload)` keyed on a device-side secret,
making clones detectable: any tag whose HMAC doesn't match its UID is rejected.

### Multi-tag history (last 5)
`g_history[5]` rolling buffer; surfaced on the Dashboard "Recent Tags" list with color
swatches and source attribution.

### Auto color preview
The web UI mirrors the tag's color into the AMS Slot 1 swatch as soon as the report
echoes back, plus the "Last Scan" panel updates immediately on read. The Quick-Write
preset buttons are bordered in the profile color too.

### Usage tracking (estimate)
The firmware tracks the number of reads per UID via the UID-map (extend `UidMap` with
`uint32_t scan_count` and `uint32_t first_seen`). This gives a rough "how many prints
since I installed this spool" indicator without needing a load-cell. Each load-after-cold
counts as one scan; for finer estimation, watch print start/end events on the report
topic.

### Quick-write presets
Every profile becomes a one-click write button on the Tag Manager tab. Click a colored
"PLA Black" button → tap blank tag → done.

---

## File summary

| File | Purpose |
|---|---|
| `SSOLite.ino` | Main firmware: state machine, RFID, MQTT, Wi-Fi, persistence, web API. |
| `web_pages.h` | HTML / CSS / JS for the embedded web UI as `PROGMEM` strings. |
| `README.md` | This document. |

## License & disclaimer
This code talks to a Bambu printer using the documented (LAN-mode) MQTT command set.
It uses **Generic** filament profiles only — it does not spoof or replicate Bambu's
proprietary RFID tag format. Use at your own risk; not affiliated with Bambu Lab.

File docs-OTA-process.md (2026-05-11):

# Publishing Firmware Updates

SmartSpool v1.3.0+ supports over-the-air (OTA) updates through Print Wizard.
This document explains how to publish a new firmware version that customer
devices will pick up automatically.

## One-time setup

### 1. Create the GitHub repository

Create a public repo at `github.com/KellyPrintCo/SmartSpool` (or fork the
existing one). Push the SSOLite firmware source plus this `version.json`
file at the repo root.

### 2. Update extension constants if you forked

If your GitHub org isn't named `KellyPrintCo`, change two constants:

**`mw-wizard/background.js`** line ~20:
```js
const VERSION_JSON_URL =
  "https://raw.githubusercontent.com/<YOUR_ORG>/SmartSpool/main/version.json";
```

**`SSOLite/web_pages.h`** (the device's own web UI updater) — search for
`VERSION_JSON` and update the URL.

## Publishing a new firmware version

Three steps. Total time: about 5 minutes.

### Step 1 — Build the firmware binary

In Arduino IDE:

1. Open `SSOLite.ino`
2. Update the `FW_VERSION` constant — increment from `1.3.0` to `1.3.1`, `1.4.0`, etc.
3. Make your code changes
4. Save the sketch
5. **Sketch → Export Compiled Binary**
6. The IDE creates a `.bin` file in the sketch folder named something like
   `SSOLite.ino.esp32.bin` or `build/esp32.esp32.esp32/SSOLite.ino.bin`
7. Rename this file to `firmware.bin`

### Step 2 — Create a GitHub Release

1. Go to `github.com/KellyPrintCo/SmartSpool/releases/new`
2. Click **"Choose a tag"** and create a new tag matching your version: `v1.3.1`
3. Set the release title to the same: `v1.3.1`
4. In the description, write the release notes (these appear in Print Wizard
   when customers see the update prompt)
5. **Attach `firmware.bin`** by dragging it into the assets area
6. Click **"Publish release"**

The firmware binary is now publicly accessible at:
```
https://github.com/KellyPrintCo/SmartSpool/releases/download/v1.3.1/firmware.bin
```

### Step 3 — Update version.json

Edit `version.json` at the repo root and commit:

```json
{
  "version": "1.3.1",
  "firmware_url": "https://github.com/KellyPrintCo/SmartSpool/releases/download/v1.3.1/firmware.bin",
  "release_notes": "Fixed UID fallback timing bug. Improved web UI on small screens.",
  "required": false,
  "min_compatible": "1.3.0"
}
```

Commit and push to `main`. Customers who open Print Wizard or the device web
UI will see the update prompt within seconds.

## version.json fields

| Field | Purpose |
|---|---|
| `version` | The new firmware version (semver: `major.minor.patch`) |
| `firmware_url` | Direct download URL for the `.bin` file from your GitHub release |
| `release_notes` | Short description shown to customers in the update prompt |
| `required` | If `true`, customers cannot skip the update — they must install it before using Print Wizard |
| `min_compatible` | The oldest firmware version the current Print Wizard extension supports. If a customer has firmware older than this, the update is required regardless of `required` field |

## When to mark `required: true`

Mark a release required only when:

- A critical security fix is in this version
- A bug in the older firmware causes data loss or device damage
- Bambu changed their MQTT API and the old firmware no longer works

Avoid making updates required for new features or minor bug fixes. The friction
annoys users who don't want to update right now.

## What customers see

**Optional update:**
- Connect to SmartSpool in Print Wizard → "Firmware update available" step
- "Update SmartSpool →" button (primary action)
- "Skip for now" button (secondary)
- Release notes shown in a callout

**Required update:**
- Same UI but the Skip button is hidden
- Customer must install before continuing to the rest of the wizard

**During update:**
- Real-time progress bar: download → upload → flash → reboot → reconnect
- Total time: typically 25-40 seconds on a normal home network
- Wizard auto-advances to filament check after success

**If update fails:**
- Error message in red, with retry option
- Device stays on the previous firmware version — never bricked
- Customer can retry, skip (if optional), or get help

## Important: the chicken-and-egg problem

**Customers on firmware older than v1.3.0 cannot OTA update** — they don't have
the OTA endpoint yet. They need to flash v1.3.0 (or newer) over USB the first
time using Arduino IDE. All subsequent updates can be OTA.

This is unavoidable. Mention it in your Etsy listing and setup guide:

> "Firmware updates happen automatically through Print Wizard once your
> SmartSpool is on v1.3.0 or later. Units shipped from June 2024 onward come
> pre-flashed with v1.3.0+ and never need manual flashing."

If you're selling assembled units, always flash the latest version before
shipping so customers never see this issue. DIY kit buyers should be directed
to install v1.3.0+ as their first flash.

## Rolling back a bad release

If you publish a release that breaks something:

1. Revert `version.json` to the previous version (commit the change)
2. New customers will get the older firmware automatically
3. Customers already on the broken version need to either:
   - Wait for you to publish a fixed version (they'll auto-update to it)
   - Flash via USB if the broken firmware is so broken it can't OTA

This is why it's worth keeping the previous firmware build around. Don't delete
old GitHub releases — they're your rollback path.

## Testing a new release before publishing

The safest workflow:

1. Build the new firmware binary
2. Flash it to a test unit via USB (don't use OTA on the test unit yet)
3. Run through your test checklist (see `SmartSpool_Test_Checklist.docx`)
4. Create the GitHub release as a **draft** first
5. Manually test OTA from the draft URL — set `VERSION_JSON_URL` to a private gist with the draft details
6. Once OTA works end-to-end, publish the release and update `version.json` on `main`

This catches the rare case where the binary itself is fine but the OTA flash
process has an issue (corrupted upload, wrong partition scheme, etc).

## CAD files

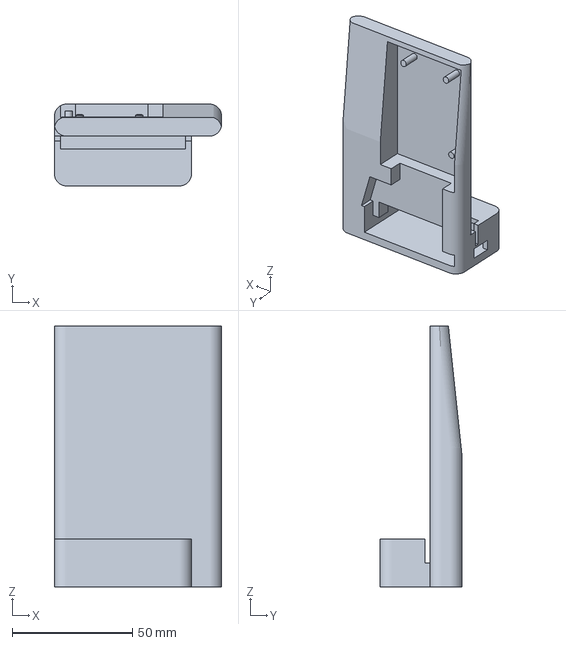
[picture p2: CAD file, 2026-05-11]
hardware/stl/SmartSpool.3mf
69.5 x 34.0 x 108.5 mm

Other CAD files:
hardware/stl/SmartSpool.stl

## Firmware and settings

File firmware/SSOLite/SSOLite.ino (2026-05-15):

/*
 * ============================================================================
 *  SmartSpool OS Lite (SSO-Lite)  v1.0
 *  ESP32 + MFRC522 -> Bambu Lab AMS Slot 1 auto-assignment over MQTT/TLS
 * ----------------------------------------------------------------------------
 *  Target board:  ESP32 DevKit V1 / WROOM-32
 *  Toolchain:     Arduino IDE 2.x  with esp32 core 2.0.x or 3.0.x
 *  Required libs:
 *    - MFRC522         by Miguel Balboa     (>= 1.4.10)
 *    - PubSubClient    by Nick O'Leary       (>= 2.8)
 *    - ArduinoJson     by Benoit Blanchon    (>= 6.21, NOT v7)
 *  All other includes ship with the ESP32 Arduino core.
 * ============================================================================
 */

#include <Arduino.h>
#include <SPI.h>
#include <MFRC522.h>
#include <WiFi.h>
#include <WiFiClientSecure.h>
#include <HTTPClient.h>
#include <PubSubClient.h>
#include <ArduinoJson.h>
#include <WebServer.h>
#include <ESPmDNS.h>
#include <Update.h>
#include <Preferences.h>
#include <vector>

#include "web_pages.h"

/* =========================================================================
 *  PIN MAP   (avoid GPIO 0/2/12/15 strap pins; 6-11 are flash; 34-39 input-only)
 * ========================================================================= */
#define PIN_RFID_SS    5     // MFRC522 SDA / SS
#define PIN_RFID_RST   22    // MFRC522 RST
// SPI default on ESP32: SCK=18, MISO=19, MOSI=23
#define PIN_LED        2     // on-board LED (status)

/* =========================================================================
 *  CONSTANTS
 * ========================================================================= */
#define FW_VERSION       "1.3.4"
#define MAGIC_HEADER     "SSO1"          // 4 bytes - identifies our tags
/* Storage spans 4 blocks across 2 sectors = 64 bytes total.
 * Sector trailers (blocks 7, 11) are NEVER touched. */
#define DATA_BLOCK_A     4                // sector 1 block 0
#define DATA_BLOCK_B     5                // sector 1 block 1
#define DATA_BLOCK_C     6                // sector 1 block 2
#define DATA_BLOCK_D     8                // sector 2 block 0
#define TAG_BLOB_SIZE    64
#define TAG_PAYLOAD_MAX  57               // 64 - 4(magic) - 1(ver) - 1(len) - 1(csum)
#define MAX_PROFILES     32
#define MAX_UID_MAPS     32
#define MAX_HISTORY      5
#define DEBOUNCE_MS      3000             // same tag twice within this window = ignored
#define MQTT_RETRY_MS    5000
#define WIFI_RETRY_MS    10000
#define ASSIGN_TIMEOUT_MS 4000

/* =========================================================================
 *  TYPES
 * ========================================================================= */
enum SystemState : uint8_t {
  STATE_BOOT, STATE_WIFI_CONNECTING, STATE_MQTT_CONNECTING,
  STATE_IDLE, STATE_READING, STATE_WRITING, STATE_ASSIGNING, STATE_ERROR
};

struct SystemConfig {
  char     wifi_ssid[33];
  char     wifi_pass[65];
  char     printer_ip[16];
  char     printer_serial[20];
  char     lan_code[17];
  bool     auto_assign;
  bool     auto_rewrite;     // v1.2: rewrite tag when touchscreen changes slot 1 info
  uint8_t  ams_id;          // pinned to 0
  uint8_t  tray_id;         // pinned to 0  (Slot 1)
};

struct FilamentProfile {
  char     name[24];        // user-friendly label
  char     material[8];     // PLA / PETG / ABS / TPU / PA / PC / PVA
  char     code[8];         // tray_info_idx, e.g. GFL99
  char     color[7];        // RRGGBB (no #)
  char     brand[20];
  uint16_t nozzle_min;
  uint16_t nozzle_max;
  uint16_t bed_temp;
  uint16_t flow_x1000;      // 1000 = 1.00x
  bool     in_use;
};

struct UidMap {                     // UID-only fallback if data blocks corrupt
  uint8_t  uid[10];
  uint8_t  uid_len;
  char     code[8];
  bool     in_use;
};

struct LastScan {
  uint8_t  uid[10];
  uint8_t  uid_len;
  FilamentProfile profile;
  uint32_t timestamp;
  bool     valid;
  bool     wrote_to_printer;
  char     source[12];      // "tag" / "uid_map" / "manual"
};

struct PendingAssign {
  FilamentProfile profile;
  uint32_t next_attempt;
  uint8_t  attempts;
  bool     pending;
};

/* v1.2: when auto_rewrite is enabled and the printer reports a slot 1 change
 * that didn't come from us, we queue a rewrite of the tag so the next scan
 * persists the user's touchscreen change to the RFID tag itself. */
struct PendingRewrite {
  uint8_t  uid[10];
  uint8_t  uid_len;
  FilamentProfile profile;
  bool     pending;
  uint32_t queued_at;
};

/* v1.3: OTA update state — tracks an in-progress firmware upload from the
 * extension.  The upload handler populates this; the completion handler
 * reads it and either reboots or reports the error. */
struct OtaState {
  bool     active;
  bool     error;
  uint32_t bytes_written;
  uint32_t total_size;
  char     error_msg[64];
};

/* =========================================================================
 *  GLOBALS
 * ========================================================================= */
MFRC522            rfid(PIN_RFID_SS, PIN_RFID_RST);
MFRC522::MIFARE_Key defaultKey;          // FFFFFFFFFFFF
WiFiClientSecure   tlsClient;
PubSubClient       mqtt(tlsClient);
WebServer          httpd(80);
Preferences        prefs;

SystemConfig       g_cfg;
SystemState        g_state = STATE_BOOT;
LastScan           g_lastScan = {};
PendingAssign      g_pending  = {};
PendingRewrite     g_pendingRewrite = {};
OtaState           g_ota           = {};
FilamentProfile    g_profiles[MAX_PROFILES];
UidMap             g_uidMaps[MAX_UID_MAPS];
LastScan           g_history[MAX_HISTORY];
uint8_t            g_historyCount = 0;
FilamentProfile    g_currentSlot1 = {};   // last reported AMS slot 1 state
bool               g_officialTagDetected = false;
uint32_t           g_lastWifiAttempt = 0;
uint32_t           g_lastMqttAttempt = 0;
uint32_t           g_lastSelfTest    = 0;

/* Pending write request, queued by web UI, executed when a tag is presented */
struct PendingWrite {
  FilamentProfile profile;
  bool     pending;
  uint32_t expires;
};
PendingWrite g_pendingWrite = {};

/* Forward declarations */
void   loadConfig();
void   saveConfig();
void   loadProfiles();
void   saveProfiles();
void   loadUidMaps();
void   saveUidMaps();
void   seedDefaultProfiles();
void   initRFID();
void   initWiFiSTA();
void   initMQTT();
void   initWebServer();
void   rfidPoll();
void   handleTag(MFRC522::Uid &uid);
bool   readTagData(FilamentProfile &out);
bool   writeTagData(const FilamentProfile &p);
bool   authBlock(uint8_t block);
String encodeProfile(const FilamentProfile &p);
bool   decodeProfile(const String &raw, FilamentProfile &out);
FilamentProfile* findProfileByCode(const char *code);
FilamentProfile* findProfileByName(const char *name);
UidMap* findUidMap(const uint8_t *uid, uint8_t len);
void   pushHistory(const LastScan &s);
void   sendAmsAssign(const FilamentProfile &p);
void   mqttCallback(char *topic, byte *payload, unsigned int len);
void   processReport(const JsonDocument &doc);
void   setLED(bool on);
void   blinkLED(uint8_t times, uint16_t ms);
String uidToHex(const uint8_t *uid, uint8_t len);
uint8_t xorChecksum(const uint8_t *data, size_t len);
/* v1.3 OTA */
void   handleOtaUpload();
void   handleOtaComplete();

/* =========================================================================
 *  SETUP / LOOP
 * ========================================================================= */
void setup() {
  Serial.begin(115200);
  delay(150);
  Serial.println();
  Serial.println(F("====================================================="));
  Serial.println(F("  SmartSpool OS Lite  v" FW_VERSION));
  Serial.println(F("====================================================="));

  pinMode(PIN_LED, OUTPUT);
  setLED(false);

  /* Persistent storage */
  prefs.begin("ssolite", false);
  loadConfig();
  loadProfiles();
  loadUidMaps();
  if (!prefs.getBool("seeded", false)) {
    seedDefaultProfiles();
    prefs.putBool("seeded", true);
    saveProfiles();
  }

  /* Hardware */
  initRFID();

  /* Network */
  initWiFiSTA();

  /* MQTT */
  tlsClient.setInsecure();        // Bambu uses a self-signed cert
  mqtt.setBufferSize(4096);       // reports can be big
  mqtt.setKeepAlive(30);
  mqtt.setSocketTimeout(10);
  initMQTT();

  /* Web UI */
  initWebServer();

  g_state = STATE_IDLE;
  Serial.println(F("[BOOT] Ready."));
  blinkLED(3, 80);
}

void loop() {
  /* Web first - keep UI responsive even when offline */
  httpd.handleClient();

  /* WiFi watchdog */
  if (WiFi.status() != WL_CONNECTED) {
    if (millis() - g_lastWifiAttempt > WIFI_RETRY_MS) {
      Serial.println(F("[WiFi] reconnecting..."));
      WiFi.reconnect();
      g_lastWifiAttempt = millis();
    }
  } else {
    /* MQTT loop only when WiFi is up */
    if (!mqtt.connected()) {
      if (millis() - g_lastMqttAttempt > MQTT_RETRY_MS) {
        initMQTT();
        g_lastMqttAttempt = millis();
      }
    } else {
      mqtt.loop();
    }
  }

  /* Process pending AMS assignment retries */
  if (g_pending.pending && millis() >= g_pending.next_attempt) {
    if (mqtt.connected()) {
      Serial.printf("[ASSIGN] retry attempt %u\n", g_pending.attempts + 1);
      sendAmsAssign(g_pending.profile);
    } else {
      g_pending.next_attempt = millis() + MQTT_RETRY_MS;
    }
  }

  /* RFID polling */
  rfidPoll();

  /* Pending write expiration */
  if (g_pendingWrite.pending && millis() > g_pendingWrite.expires) {
    Serial.println(F("[WRITE] queued write expired, cancelling."));
    g_pendingWrite.pending = false;
  }

  delay(15);
}

/* =========================================================================
 *  CONFIG PERSISTENCE
 * ========================================================================= */
void loadConfig() {
  prefs.getString("wifi_ssid", g_cfg.wifi_ssid, sizeof(g_cfg.wifi_ssid));
  prefs.getString("wifi_pass", g_cfg.wifi_pass, sizeof(g_cfg.wifi_pass));
  prefs.getString("printer_ip", g_cfg.printer_ip, sizeof(g_cfg.printer_ip));
  prefs.getString("printer_sn", g_cfg.printer_serial, sizeof(g_cfg.printer_serial));
  prefs.getString("lan_code",  g_cfg.lan_code, sizeof(g_cfg.lan_code));
  g_cfg.auto_assign  = prefs.getBool("auto_assign", true);
  g_cfg.auto_rewrite = prefs.getBool("auto_rewrite", false);   // off by default
  g_cfg.ams_id  = 0;
  g_cfg.tray_id = 0;
  Serial.printf("[CFG] ssid=%s ip=%s sn=%s auto=%d rewrite=%d\n",
                g_cfg.wifi_ssid, g_cfg.printer_ip, g_cfg.printer_serial,
                g_cfg.auto_assign, g_cfg.auto_rewrite);
}

void saveConfig() {
  prefs.putString("wifi_ssid", g_cfg.wifi_ssid);
  prefs.putString("wifi_pass", g_cfg.wifi_pass);
  prefs.putString("printer_ip", g_cfg.printer_ip);
  prefs.putString("printer_sn", g_cfg.printer_serial);
  prefs.putString("lan_code",  g_cfg.lan_code);
  prefs.putBool  ("auto_assign",  g_cfg.auto_assign);
  prefs.putBool  ("auto_rewrite", g_cfg.auto_rewrite);
}

/* =========================================================================
 *  PROFILES
 * ========================================================================= */
void seedDefaultProfiles() {
  memset(g_profiles, 0, sizeof(g_profiles));
  struct Seed { const char *name, *mat, *code, *color, *brand; uint16_t nmin,nmax,bed; };
  const Seed defaults[] = {
    {"Generic PLA Black",   "PLA",  "GFL99", "000000", "Generic",   190,230, 60},
    {"Generic PLA White",   "PLA",  "GFL99", "FFFFFF", "Generic",   190,230, 60},
    {"Generic PLA Red",     "PLA",  "GFL99", "C8161D", "Generic",   190,230, 60},
    {"Generic PLA Blue",    "PLA",  "GFL99", "0066CC", "Generic",   190,230, 60},
    {"Overture PLA Matte",  "PLA",  "GFL99", "1C1C1C", "Overture",  200,220, 60},
    {"Generic PETG",        "PETG", "GFG99", "0099A8", "Generic",   230,255, 75},
    {"Generic PETG Black",  "PETG", "GFG99", "000000", "Generic",   230,255, 75},
    {"Generic ABS",         "ABS",  "GFB99", "F2F2F2", "Generic",   240,270, 95},
    {"Generic TPU 95A",     "TPU",  "GFU99", "FFFFFF", "Generic",   220,240, 50},
    {"Generic PA (Nylon)",  "PA",   "GFN99", "303030", "Generic",   260,290, 80},
    {"Generic PC",          "PC",   "GFC99", "F0F0F0", "Generic",   270,290, 100},
    {"Generic PVA Support", "PVA",  "GFS99", "F4E2B8", "Generic",   200,210, 60},
  };
  size_t n = sizeof(defaults)/sizeof(defaults[0]);
  for (size_t i = 0; i < n && i < MAX_PROFILES; i++) {
    auto &p = g_profiles[i];
    strncpy(p.name,     defaults[i].name,  sizeof(p.name)-1);
    strncpy(p.material, defaults[i].mat,   sizeof(p.material)-1);
    strncpy(p.code,     defaults[i].code,  sizeof(p.code)-1);
    strncpy(p.color,    defaults[i].color, sizeof(p.color)-1);
    strncpy(p.brand,    defaults[i].brand, sizeof(p.brand)-1);
    p.nozzle_min = defaults[i].nmin;
    p.nozzle_max = defaults[i].nmax;
    p.bed_temp   = defaults[i].bed;
    p.flow_x1000 = 1000;
    p.in_use     = true;
  }
  Serial.printf("[PROFILES] seeded %u defaults\n", (unsigned)n);
}

void loadProfiles() {
  size_t got = prefs.getBytes("profiles", g_profiles, sizeof(g_profiles));
  if (got != sizeof(g_profiles)) {
    memset(g_profiles, 0, sizeof(g_profiles));
  }
}

void saveProfiles() {
  prefs.putBytes("profiles", g_profiles, sizeof(g_profiles));
}

void loadUidMaps() {
  size_t got = prefs.getBytes("uidmaps", g_uidMaps, sizeof(g_uidMaps));
  if (got != sizeof(g_uidMaps)) memset(g_uidMaps, 0, sizeof(g_uidMaps));
}

void saveUidMaps() {
  prefs.putBytes("uidmaps", g_uidMaps, sizeof(g_uidMaps));
}

FilamentProfile* findProfileByCode(const char *code) {
  for (auto &p : g_profiles) if (p.in_use && strcmp(p.code, code) == 0) return &p;
  return nullptr;
}
FilamentProfile* findProfileByName(const char *name) {
  for (auto &p : g_profiles) if (p.in_use && strcmp(p.name, name) == 0) return &p;
  return nullptr;
}
UidMap* findUidMap(const uint8_t *uid, uint8_t len) {
  for (auto &m : g_uidMaps) {
    if (!m.in_use) continue;
    if (m.uid_len != len) continue;
    if (memcmp(m.uid, uid, len) == 0) return &m;
  }
  return nullptr;
}

/* =========================================================================
 *  RFID
 * ========================================================================= */
void initRFID() {
  SPI.begin();                          // SCK=18 MISO=19 MOSI=23
  rfid.PCD_Init();
  delay(50);
  for (uint8_t i = 0; i < 6; i++) defaultKey.keyByte[i] = 0xFF;
  byte v = rfid.PCD_ReadRegister(MFRC522::VersionReg);
  Serial.printf("[RFID] MFRC522 firmware version: 0x%02X\n", v);
  if (v == 0x00 || v == 0xFF) {
    Serial.println(F("[RFID] WARNING - reader not responding. Check wiring/power."));
  }
}

/* Auth cache state - file-scope so we can clear it from elsewhere. */
static int8_t  s_authedSector = -1;
static uint8_t s_authedUid[10] = {0};
static uint8_t s_authedUidLen = 0;

void invalidateAuthCache() {
  s_authedSector = -1;
  s_authedUidLen = 0;
}

bool authBlock(uint8_t block) {
  /* MFRC522 quirk: once authenticated to a sector, re-authenticating to
   * another block in the SAME sector often fails on bargain RC522 boards.
   * We track the currently-authed sector and skip the auth if the next
   * block is in the same sector. Sectors 0-31 each contain 4 blocks:
   * blocks 0-3 = sector 0, blocks 4-7 = sector 1, blocks 8-11 = sector 2, etc.
   *
   * NOTE: Call invalidateAuthCache() whenever PCD_StopCrypto1 or PICC_HaltA
   * is invoked, so the next auth on the same card re-runs PCD_Authenticate. */
  uint8_t sector = block / 4;

  bool sameCard = (s_authedUidLen == rfid.uid.size) &&
                  (memcmp(s_authedUid, rfid.uid.uidByte, rfid.uid.size) == 0);

  if (sameCard && s_authedSector == (int8_t)sector) {
    /* Already authed to this sector for this card - nothing to do. */
    return true;
  }

  auto status = rfid.PCD_Authenticate(MFRC522::PICC_CMD_MF_AUTH_KEY_A, block,
                                      &defaultKey, &(rfid.uid));
  if (status != MFRC522::STATUS_OK) {
    Serial.printf("[AUTH] block %u (sector %u) FAIL status=%d\n", block, sector, status);
    s_authedSector = -1;
    s_authedUidLen = 0;
    return false;
  }
  Serial.printf("[AUTH] block %u (sector %u) OK\n", block, sector);
  s_authedSector = sector;
  s_authedUidLen = rfid.uid.size;
  memcpy(s_authedUid, rfid.uid.uidByte, rfid.uid.size);
  return true;
}

void rfidPoll() {
  /* PICC_IsNewCardPresent has to be called repeatedly; it does not block */
  if (!rfid.PICC_IsNewCardPresent()) return;
  if (!rfid.PICC_ReadCardSerial())   return;

  /* Detect Bambu official tag (heuristic: tag is NTAG/ULTRALIGHT, NOT MIFARE Classic).
   * Real Bambu spools use NTAG216 in some revisions; we are not allowed to spoof,
   * so when we see a non-Classic tag we *disable* automation for safety. */
  MFRC522::PICC_Type t = rfid.PICC_GetType(rfid.uid.sak);
  if (t != MFRC522::PICC_TYPE_MIFARE_1K &&
      t != MFRC522::PICC_TYPE_MIFARE_4K &&
      t != MFRC522::PICC_TYPE_MIFARE_MINI) {
    g_officialTagDetected = true;
    Serial.println(F("[RFID] Non-Classic tag (likely Bambu/NTAG). Auto-assign disabled."));
    rfid.PICC_HaltA();
    rfid.PCD_StopCrypto1();
    invalidateAuthCache();
    return;
  }
  g_officialTagDetected = false;

  handleTag(rfid.uid);

  rfid.PICC_HaltA();
  rfid.PCD_StopCrypto1();
  invalidateAuthCache();
}

void handleTag(MFRC522::Uid &uid) {
  /* Debounce identical UID */
  bool sameUid = (uid.size == g_lastScan.uid_len) &&
                 (memcmp(uid.uidByte, g_lastScan.uid, uid.size) == 0);
  uint32_t now = millis();
  if (sameUid && g_lastScan.valid && (now - g_lastScan.timestamp < DEBOUNCE_MS)) {
    return;   // ignore bounces
  }

  Serial.printf("[RFID] tag UID=%s\n", uidToHex(uid.uidByte, uid.size).c_str());
  setLED(true);

  /* If web UI queued a write request, fulfil it now */
  if (g_pendingWrite.pending) {
    Serial.println(F("[WRITE] writing pending profile to tag..."));
    bool ok = writeTagData(g_pendingWrite.profile);
    Serial.printf("[WRITE] result: %s\n", ok ? "OK" : "FAIL");
    g_pendingWrite.pending = false;
    blinkLED(ok ? 2 : 5, 80);
    setLED(false);
    return;
  }

  /* Probe block 4 with the default key. If auth fails, this is almost
   * certainly a Bambu spool tag — same MIFARE Classic chip but locked
   * with a non-default key. Treat it like a "non-Classic" official tag:
   * mark the lock pill active, disable auto-assign, and do not attempt
   * to read or write. */
  if (!authBlock(DATA_BLOCK_A)) {
    g_officialTagDetected = true;
    Serial.println(F("[RFID] Official tag detected (auth fail on default key). Auto-assign disabled."));
    Serial.println(F("       Use a fresh MIFARE 1K sticker for SmartSpool tags."));
    blinkLED(3, 100);
    setLED(false);
    return;
  }
  /* If we got here, block 4 authed successfully — this tag uses the default
   * key, so it's safe to read/write. Clear the official-tag flag in case it
   * was set by a previous non-Classic scan. */
  g_officialTagDetected = false;

  /* v1.2: auto-rewrite — if there's a queued tag rewrite for THIS UID
   * (printer reported a slot 1 change since this tag was last scanned),
   * write the new profile to the tag before doing the normal read flow. */
  if (g_cfg.auto_rewrite && g_pendingRewrite.pending &&
      g_pendingRewrite.uid_len == uid.size &&
      memcmp(g_pendingRewrite.uid, uid.uidByte, uid.size) == 0) {
    Serial.println(F("[REWRITE] applying queued touchscreen change to tag..."));
    bool ok = writeTagData(g_pendingRewrite.profile);
    Serial.printf("[REWRITE] result: %s\n", ok ? "OK" : "FAIL");
    g_pendingRewrite.pending = false;
    /* Fall through into the normal read path so we still update the AMS
     * with the new profile and refresh history. The tag now contains the
     * new data, so readTagData() below will read the freshly written
     * payload. */
    if (!ok) {
      blinkLED(5, 80);
      setLED(false);
      return;
    }
  }

  /* Read tag data */
  FilamentProfile p = {};
  bool readOk = readTagData(p);
  const char *src = "tag";

  if (!readOk) {
    /* Fallback to UID map */
    UidMap *m = findUidMap(uid.uidByte, uid.size);
    if (m) {
      FilamentProfile *fp = findProfileByCode(m->code);
      if (fp) { p = *fp; readOk = true; src = "uid_map"; }
    }
  }

  if (!readOk) {
    Serial.println(F("[RFID] tag unreadable and no UID mapping."));
    blinkLED(4, 60);
    setLED(false);
    return;
  }

  /* Resolve to local profile.
   *
   * The tag is the source of truth for COLOR and CODE (the user wrote
   * those deliberately). The local profile, if found, only contributes
   * canonical immutable fields (temperatures, flow, full name) so different
   * tag generations stay consistent.
   *
   * Previously this entire profile was overwritten, which threw away the
   * color the user just wrote to the tag and made every "Generic PLA"
   * variant show as the black default. */
  FilamentProfile *known = findProfileByCode(p.code);
  if (known) {
    /* Copy canonical fields only; keep the tag's color and (already-set) code. */
    strncpy(p.material,  known->material, sizeof(p.material)-1);
    strncpy(p.brand,     known->brand,    sizeof(p.brand)-1);
    p.nozzle_min = known->nozzle_min;
    p.nozzle_max = known->nozzle_max;
    p.bed_temp   = known->bed_temp;
    p.flow_x1000 = known->flow_x1000;
    /* Update display name to reflect the tag's actual color when possible. */
    snprintf(p.name, sizeof(p.name), "%s %s", p.brand, p.material);
  }

  /* Update last-scan and history */
  memcpy(g_lastScan.uid, uid.uidByte, uid.size);
  g_lastScan.uid_len = uid.size;
  g_lastScan.profile = p;
  g_lastScan.timestamp = now;
  g_lastScan.valid = true;
  g_lastScan.wrote_to_printer = false;
  strncpy(g_lastScan.source, src, sizeof(g_lastScan.source)-1);
  pushHistory(g_lastScan);

  /* Auto-assign */
  if (g_cfg.auto_assign && !g_officialTagDetected) {
    sendAmsAssign(p);
  }

  blinkLED(2, 60);
  setLED(false);
}
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

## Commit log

2026-05-11 Improve error messages and device discovery
    [SSOLite.ino]
2026-05-15 Fixed Print Wizard "open in Bambu Studio"
